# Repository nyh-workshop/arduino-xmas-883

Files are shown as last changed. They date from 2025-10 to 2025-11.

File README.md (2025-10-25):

# arduino-xmas-883
An improvisation of Myke Predko's "xmas" project in "Programming and Customizing the PIC Microcontroller 3rd Edition"

*Note*: This has been attempted in my other [repository](https://github.com/nyh-workshop/arduino-xmas-883-2023) too in 2023. However this one is a more detailed version and there are example STL and Gerber files for the materials.

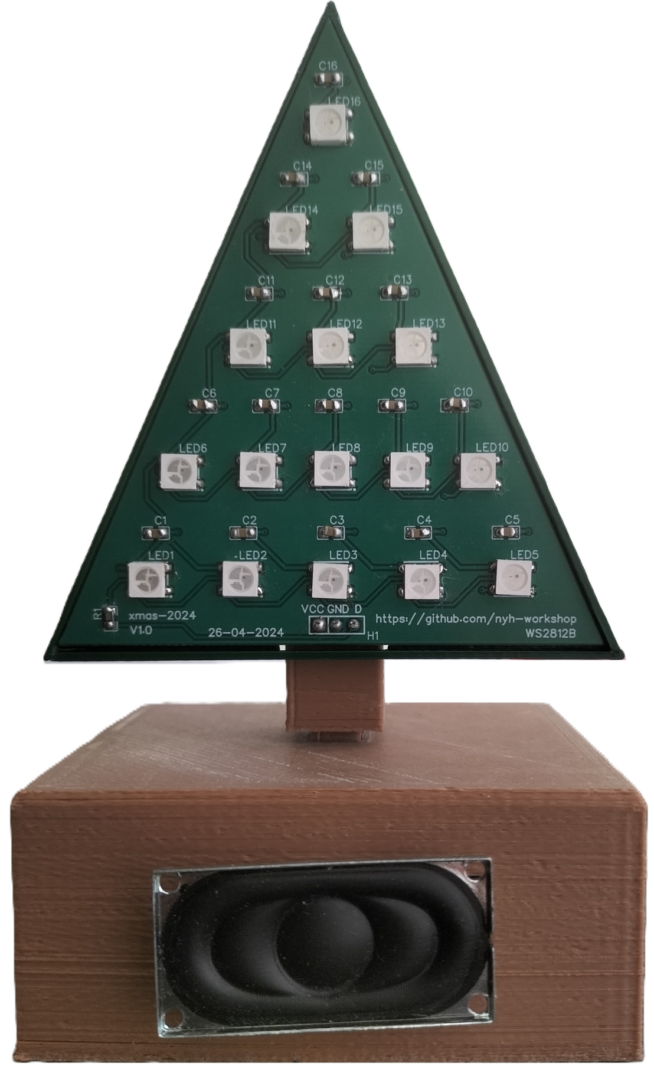
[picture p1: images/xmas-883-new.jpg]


## Introduction
About some 17 years back when I was in college, I chanced upon the Myke Predko's *Programming and Customizing the PIC Microcontroller* book in a local bookstore when I wanted to find study materials on microcontroller subject next semester.

It was extremely expensive over there in the place I stay and I could only glance a few pages of the book for previewing.

While admiring the projects in the book I saw one of the projects in page 883 called `xmas`, caught my attention and tried to remember as much details as possible.

Little me didn't know I could make things like that with a PIC microcontroller! Since I had a lot of space constraints at home, having a miniature, singing Christmas tree would be so cool on *my very own desk*!

I had attempted variants of this one almost each year - each of them are different every season, from one WAV file player, to another with different amount of LEDs, and with different microcontrollers from PIC32 to even ESP32. That too polished up some of the embedded skills of course!

## Details of the original `xmas`
### Random blinky lights
- From the schematic the author uses a `PIC16F84` microcontroller, coupled with a few `74LS373` shift registers to expand the I/O to accomodate those 16 LEDs.

- There is a pseudo-random number generator written to generate a random LED pattern, which is then manually bit-banged into the `74LS373`.

- The author mentioned about *wiring these 16 LEDs one-by-one* to the back of the tree, with many wires being used. Yes, it is tedious!

### Music
- It is a square-wave, monophonic. Bit-banged through a GPIO pin.

- The tone generation and reading the "notes" in the array is using a timer interrupt, possibly a `TMR0` one.

- The author recommends to use a beginner's Christmas music piano book to put these notes into the array manually. It has to be with the certain frequency range.

### Construction
- The original one uses **wood pieces and some paint**. Basically, the triangle one uses green and the base could be a brown to simulate the wood color.

- The PCB is manually sketched and etched locally. It is attached to the back of the tree "trunk" (*see diagram*).

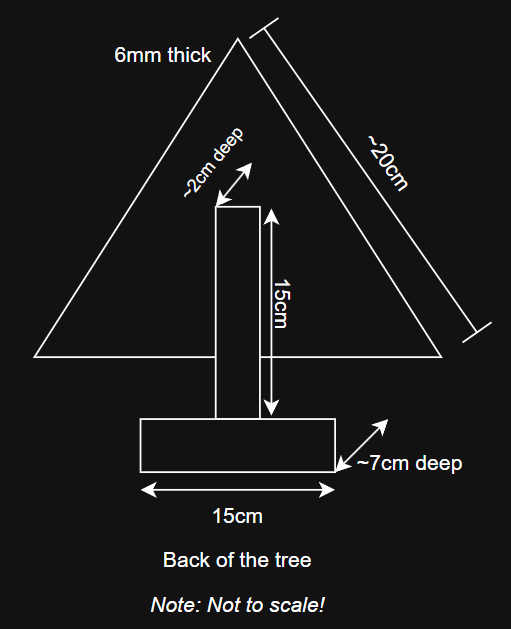
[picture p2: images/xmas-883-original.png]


### Power
- It is powered through the DC jack, with the casual 7805.

## Details of the improvised `xmas` in 2025
### Random blinky lights (and more colorful LEDs!)
- Using the [WS2811/WS2812 addressable LEDs](https://cdn-shop.adafruit.com/datasheets/WS2812.pdf). Saves me the time from wiring the LEDs and also these LEDs can display any 24-bit RGB color. Plus, many libraries such as [FastLED](https://fastled.io/) offers support for these LEDs without having to rewrite special LED effects again.

- Instead of a PIC microcontroller, a [Raspberry Pico 2](https://www.raspberrypi.com/products/raspberry-pi-pico-2/) is used instead with the [Arduino Pico library](https://github.com/earlephilhower/arduino-pico). There is PIO (Programmable I/O) modules that helps to generate WS2812 signals without CPU intervention.

- This blinky activity is entirely run on core0 of this microcontroller.

- Soldering them on a PCB (Gerber included here) is even easier. It's all on the board!

### Music
- This uses a [modified MicroDexed library](https://codeberg.org/nyh-workshop/MicroDexed) for the Raspberry Pico 2 Arduino platform. Basically it is a Yamaha DX7 emulator. This generates the popular FM soundwaves that you hear from the 80s music.

- And, of course we need the music notes inside! I have the [modified MD_MIDIFile that reads the MIDI from the Raspberry Pico 2's flash memory](https://github.com/nyh-workshop/MD_MIDIFile_LittleFS). This saves me the extra SD card that I might use later. There is an Arduino plugin that [uploads the files into the Pico 2's flash memory](https://github.com/earlephilhower/arduino-pico-littlefs-plugin) too.

- Best of all it covers most of the frequency of the music notes!

- It is output through the [MAX98357 module](https://learn.adafruit.com/adafruit-max98357-i2s-class-d-mono-amp/overview), with a small speaker.

- The music playing and the emulator is running on another core1 of this microcontroller.

### Power
- It is powered through the regular micro-USB.

### Construction
- The original one was a bit too big for my desk or on my shelves, so I made the tree smaller.

- It has a multi-purpose PCB mainboard (check the Hardware folder) where I can mount the Pico 2, the MAX98357 module, the optional [M5 Unit Synth](https://docs.m5stack.com/en/unit/Unit-Synth) connector and the WS2811 port there. Gerbers are included if you want to send it to popular PCB manufacturers.

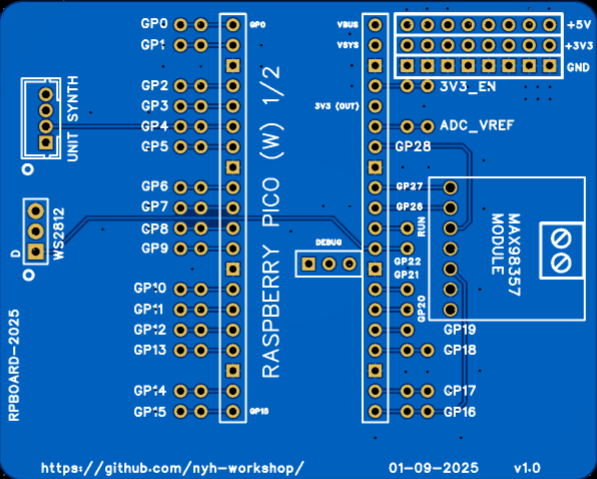
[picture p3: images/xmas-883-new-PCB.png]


- The WS2812 LEDs are mounted on the triangle portion of the tree. It is also a PCB for convenience sake.

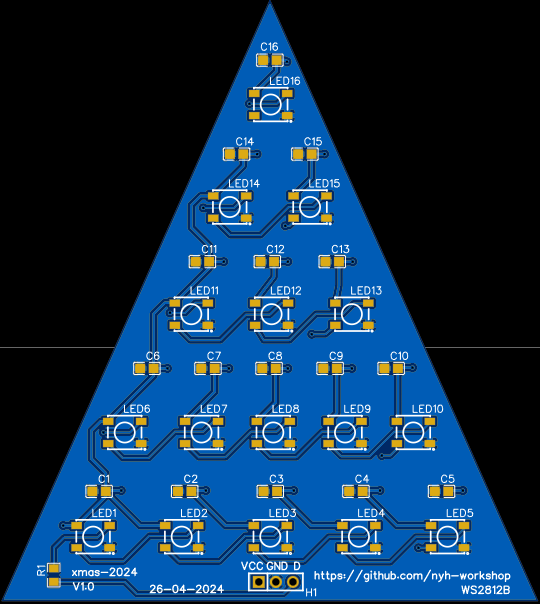
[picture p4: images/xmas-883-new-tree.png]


#### 3D printed tree and body

Since I can't *easily* source any wood pieces right now (or even before), it would be much easier if I just 3D-print it.

Similarly, I used the 3D-print `forest green` filament for the tree part (triangle), and the rest of the base and the trunk with `brown` filament.

I drew the parts using **Fusion 360**. It consists of the box that holds the mainboard box, its base, the trunk, and finally the tree part:

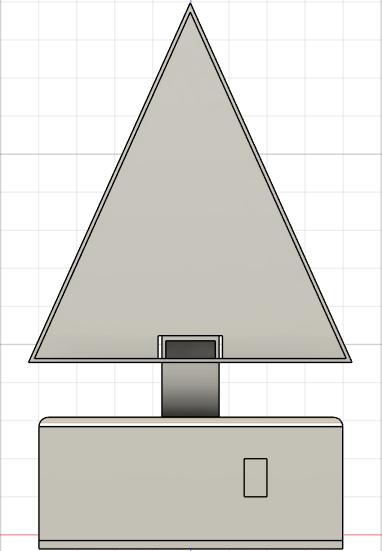
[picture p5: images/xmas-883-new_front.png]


From the original, mounting the PCB at the back of the tree is possibly impractical due to the location of the USB port. So, instead of putting it at the back, I choose to put it into the box, with the speaker glued to the front of the box.

Here is the construction when the board is fitted onto the box tray, with kapton tapes securing the wires:
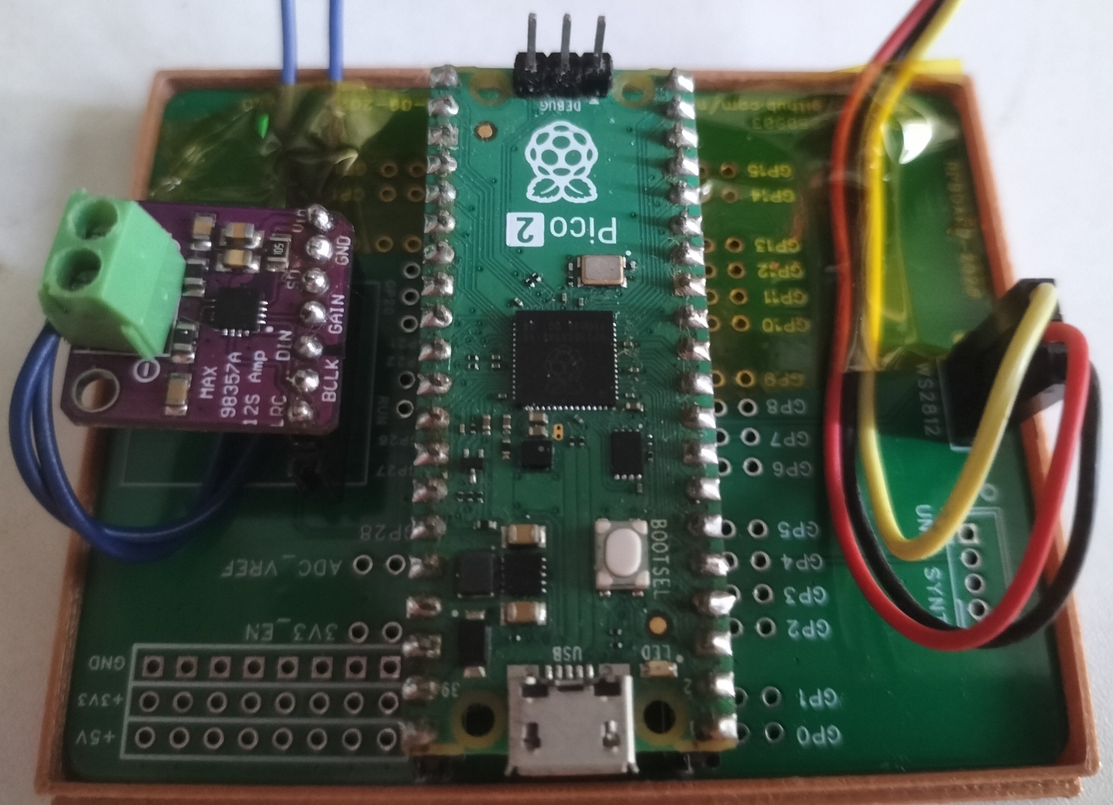
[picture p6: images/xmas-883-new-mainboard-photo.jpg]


To fit the PCB tree part to the 3D-print tree part (the triangle one), it is recommended that you use a double-sided tape to hold these together firmly.

There's a small rectangular hole in front of the box - it is slightly to the right. It is for the wires for the **small rectangular speaker (8 ohms, 2 watts)** and these are connected to the MAX98357 module's output. Again, use a double-sided tape to mount the speaker in front of the box.

### Software
For the LED part, the "blinky" is more than just blink now - there are all the colors in the world! I have used the FastLED example `Demoreel 100` and modified with some extra effects such as twinkling and such.

You can get the Christmas MIDIs from online, and then put these into the `data` folder before doing the `Upload LittleFS to Pico`. Make sure you have select the `Flash Size 128KB` or more at the `Tools` section.

For better playability of the MIDI file it is recommended that:
- Only one track is used. Multitrack may not work well on it.
- Keep the voices around 11 maximum.
- It does not play multiple instruments - only one is played. This will closely "imitate" the original design which is only a square-wave.

To modify the MIDI files back to one track and other things to accomodate the player, apps such as [MidiEditor](http://www.midieditor.org/) can be used.

As the player can support different instrument sounds, I have programmed it to play a different instrument every each time you switch it on. 

### Issues
- Since the MicroDexed is pretty CPU-intensive, I do expect a small amount of stuttering during playback. On testing, sometimes the MIDI player **behaved erratically** and have **too many notes ringing** at once. This causes the playback to stutter and eventually sounding off-key in a terrible manner. To minimize that unusual stuttering and stalling, I have enabled the `STUTTER_REBOOT` to **force reboot** the system when this happened. If it is disabled, the core1 will **halt** there while the LED blinks at the fastest way possible.

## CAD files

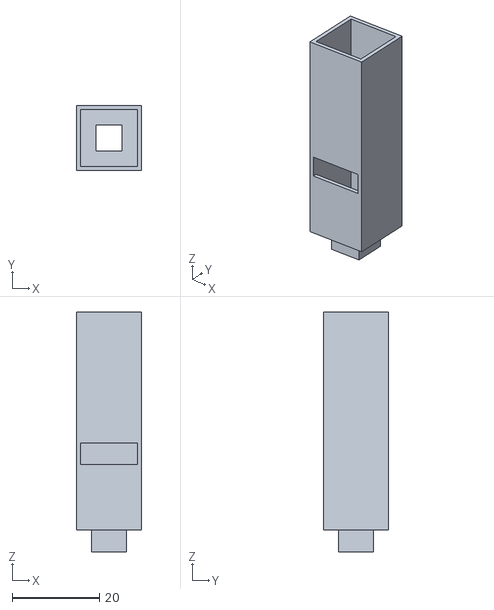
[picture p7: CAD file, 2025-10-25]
Hardware/v1.0/trunk_v1.0.stl
15.0 x 15.0 x 55.0

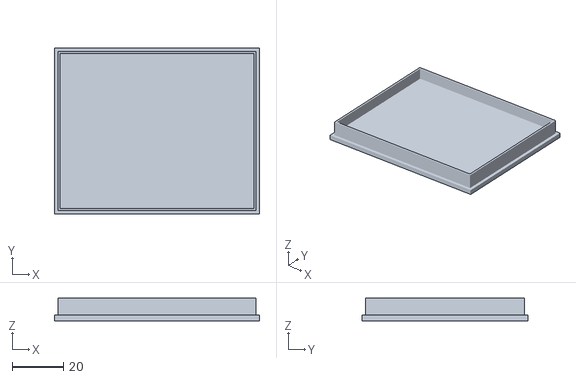
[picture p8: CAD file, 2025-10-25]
Hardware/v1.0/box_base_v1.0.stl
79.8 x 64.8 x 8.80

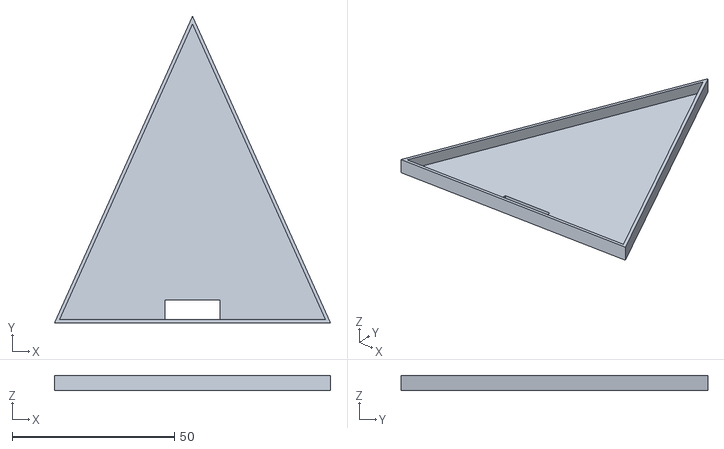
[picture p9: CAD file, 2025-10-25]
Hardware/v1.0/tree_v1.0.stl
85.0 x 94.4 x 4.50

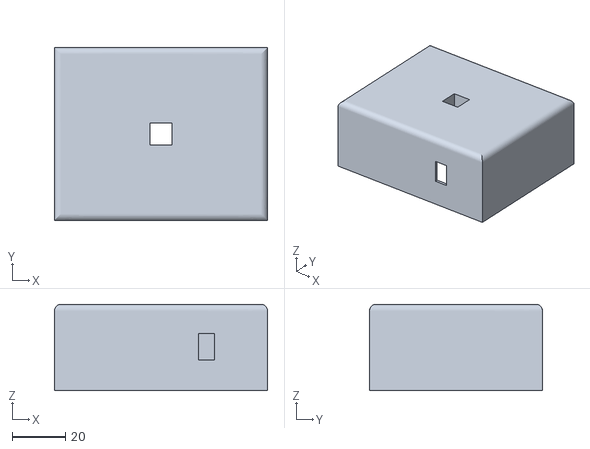
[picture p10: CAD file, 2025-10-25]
Hardware/v1.0/box_body_v1.0.stl
79.8 x 64.8 x 32.4

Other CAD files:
Hardware/v1.0/xmas-883_v1.0.f3d

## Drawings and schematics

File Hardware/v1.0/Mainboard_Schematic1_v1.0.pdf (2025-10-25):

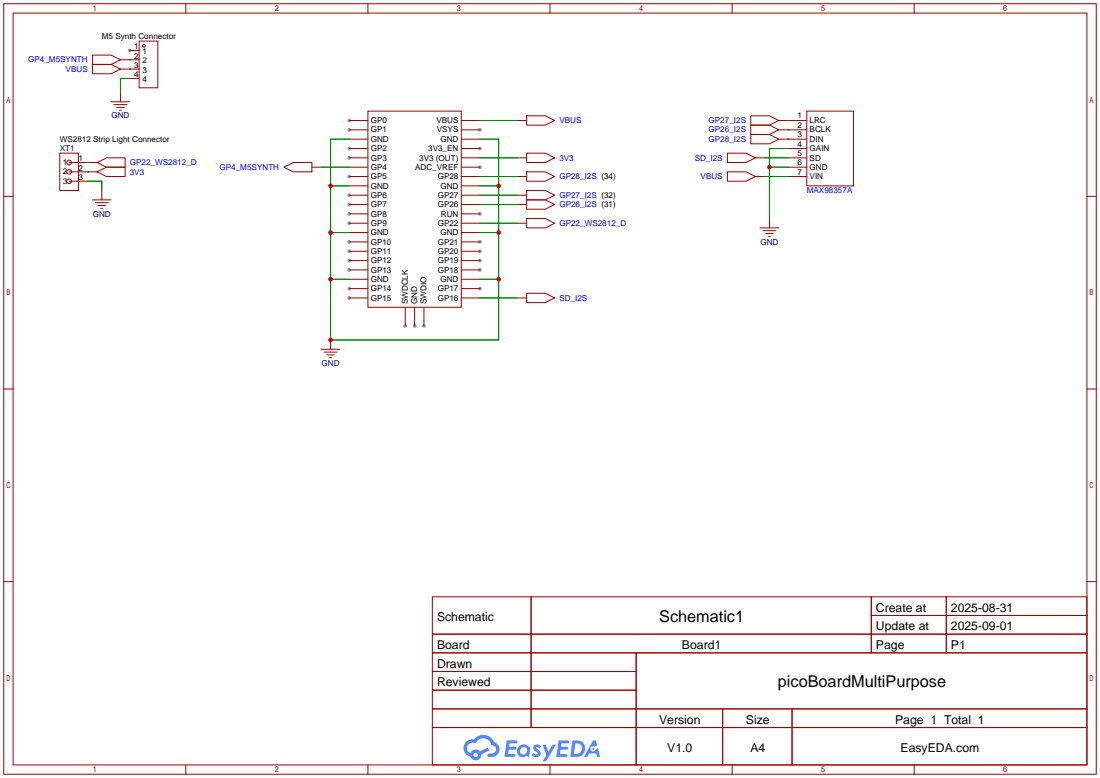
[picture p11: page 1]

Schematic | Schematic1 | Create at | 2025-08-31

Update at | 2025-09-01

Board | Board1 | Page | P1
Drawn | | picoBoardMultiPurpose
Reviewed

Version | Size | Page 1 Total 1
V1.0 | A4 | EasyEDA.com

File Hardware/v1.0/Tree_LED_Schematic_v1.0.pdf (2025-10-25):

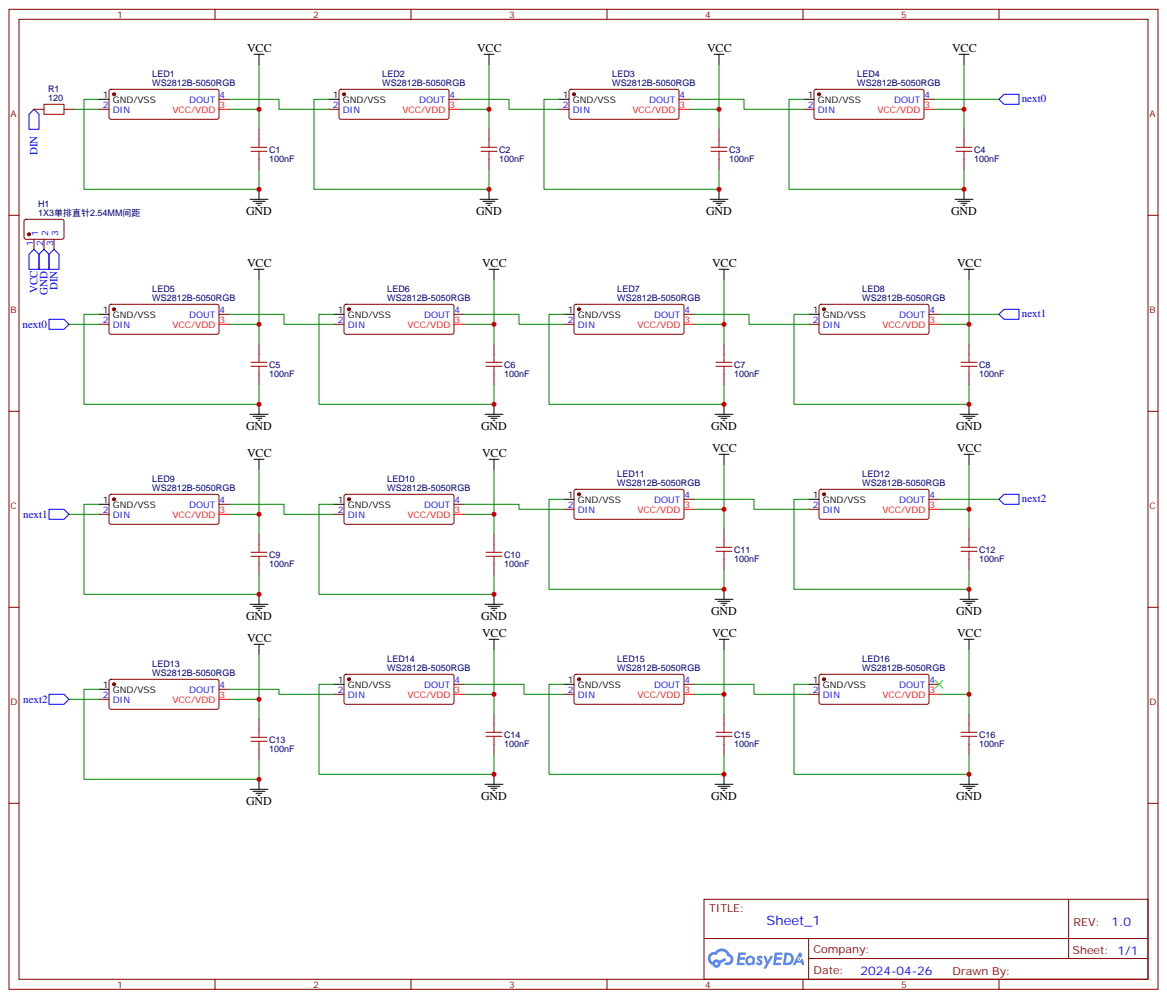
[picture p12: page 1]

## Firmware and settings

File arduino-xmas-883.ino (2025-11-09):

#include <Wire.h>
#include <limits.h>

#include <MD_MIDIFile.h>
#include <LittleFS.h>
#include <MicroDexedArduino.h>

#include "xmasLights_fastLED.h"
#include "midiJukebox.h"

// Note: Not sure why it doesn't work on Arduino Pico 5.3.0 or below! (Asserts on DMA setting at I2S)

#define LED_PIN 25
#define MAX98357_SD 16

constexpr bool DEBUG_MODE = true;

const int LED_TOGGLE_TIME_SETUP_DONE = 1000;
const int LED_TOGGLE_TIME_SETUP_ERROR = 250;
int LedToggleTime = 0;
bool LedState = false;
static uint32_t previousLedToggleTime = 0;

MicroDexedPicoI2sAudio* pMdI2s = nullptr;
Dexed* dexed = nullptr;
MD_MIDIFile SMF;
Dir rootDir;

uint32_t fill_audio_buffer = 0;
uint32_t t0, t1 = 0; // Time taken for MicroDexed engine to generate samples!
const uint16_t audio_block_time_us = 1000000 / (SAMPLE_RATE / AUDIO_BLOCK_SAMPLES);

const uint32_t MAX_STUTTERS_PER_SECOND = 16;
volatile uint32_t numberOfStuttersPerSecond = 0;
const bool STUTTER_REBOOT = true;

static enum { S_IDLE,
              S_PLAYING,
              S_NEXT,
              S_RESTART } state = S_IDLE;
static enum { SETUP_PROGRESS,
              SETUP_DONE_WITH_ERROR,
              SETUP_DONE } setupState = SETUP_PROGRESS;
static enum { DEXED_EPIANO = 11,
              DEXED_GUITAR = 12,
              DEXED_GLOCKENSPIEL_2 = 30,
              DEXED_HANDBELL_1 = 31 } dexedInstruments = DEXED_EPIANO;

uint8_t pickDexedVoice = DEXED_EPIANO;

void midiSilence(void)
// Turn everything off on every channel.
// Some midi files are badly behaved and leave notes hanging, so between songs turn
// off all the notes and sound
{
  midi_event ev;

  // All sound off
  // When All Sound Off is received all oscillators will turn off, and their volume
  // envelopes are set to zero as soon as possible.
  ev.size = 0;
  ev.data[ev.size++] = 0xb0;
  ev.data[ev.size++] = 120;
  ev.data[ev.size++] = 0;

  for (ev.channel = 0; ev.channel < 16; ev.channel++)
    midiCallback(&ev);
}

void midiCallback(midi_event* pev)
// Called by the MIDIFile library when a file event needs to be processed
// thru the midi communications interface.
// This callback is set up in the setup() function.
{
  // Define constants for MIDI channel voice message IDs
  const uint8_t NOTE_OFF = 0x80;  // note on
  const uint8_t NOTE_ON = 0x90;   // note off. NOTE_ON with velocity 0 is same as NOTE_OFF

  switch (pev->data[0]) {
    case NOTE_OFF:  // [1]=note no, [2]=velocity
      dexed->keyup(pev->data[1]);
      Serial.printf("NOTE_OFF ch: %d\n", pev->data[1]);
      break;

    case NOTE_ON:  // [1]=note_no, [2]=velocity
      // Note ON with velocity 0 is the same as off
      // Velocity is not included for now!
      dexed->keydown(pev->data[1], 127);
      Serial.printf("NOTE_ON trk: %d, ch: %d, no: %d\n", pev->track, pev->channel, pev->data[1]);
      break;

    default:
      break;
  }
}

void dexedPlaySamples() {
  // Main sound calculation
  fill_audio_buffer = micros();
  if ((i2s.availableForWrite() >= AUDIO_BLOCK_SAMPLES) && (fill_audio_buffer > (audio_block_time_us - 10))) {
    fill_audio_buffer = 0;
    t0 = micros();
    dexed->getSamples(AUDIO_BLOCK_SAMPLES, pMdI2s->audio_buffer);
    t1 = micros();
    if((t1 - t0) > audio_block_time_us)
    {
      // Serial.printf("Exceeded calculation time! %d microsecs.\n", (t1 - t0));
      numberOfStuttersPerSecond++;
    }
    pMdI2s->playSamples(AUDIO_BLOCK_SAMPLES, pMdI2s->audio_buffer);
  }
}

// Get random number from the rp2040/rp2350's hardware pseudo-random generator:
uint32_t getRandomNumber(uint32_t min, uint32_t max) {
  uint32_t randomNumber = rp2040.hwrand32();
  return (uint32_t)((randomNumber % (max - min + 1)) + min);
}

void nextSong(String midiFileName) {

  // Shut off notes at dexed during change
  // to prevent notes from going out of sync at next song!!
  dexed->notesOff();
  dexed->doRefreshVoice();
  dexed->panic();

  int err = SMF.load(midiFileName.c_str());
  if (midiFileName == "NoMoreMidiFileInDir") {
    Serial.println("No more midi files in directory!");
    return;
  }

  Serial.printf("Filename: %s\n", SMF.getFilename());
  Serial.printf("Format: %d\n", SMF.getFormat());

  if (err != MD_MIDIFile::E_OK)
    Serial.printf("SMF load error during playing: %d\n", err);
  else
    SMF.restart();
}

void stutterCheck()
{
  static uint32_t previousTime;
  if(millis() - previousTime >= 1000)
  {
    // Serial.printf("Stutters per second: %d\n", numberOfStuttersPerSecond);
    if(numberOfStuttersPerSecond > MAX_STUTTERS_PER_SECOND)
    {
      Serial.printf("Too much stuttering, exceeding max. number of stutter! %d\n", numberOfStuttersPerSecond);

      if(STUTTER_REBOOT)
        rp2040.reboot();
      else
      {
        while(1)
        {
           digitalWrite(LED_PIN, HIGH);
           delay(100);
           digitalWrite(LED_PIN, LOW);
           delay(100);
        }
      }
    }
    numberOfStuttersPerSecond = 0;
    previousTime = millis();
  }
}

void setup() {
  Serial.begin(115200);
  Serial1.begin(115200);

  uint32_t randomNumber = getRandomNumber(0, 3);

  delay(1000);

  Serial.println("arduino-xmas-883-2025");
  Serial.printf("Random number on startup: %d\n", randomNumber);

  pinMode(LED_PIN, OUTPUT);
  pinMode(WS2812_PIN, OUTPUT);

  Serial.println("Starting FastLED!");
  setupXmasLights();

  // Switch off the MAX98357 module first before init MicroDexed and I2S interface!
  pinMode(MAX98357_SD, OUTPUT);
  digitalWrite(MAX98357_SD, LOW);

  Serial.println(F("MicroDexed based on https://github.com/asb2m10/dexed"));
  Serial.println(F("(c)2018,2019-2025 H. Wirtz <wirtz@parasitstudio.de>"));
  Serial.println(F("https://github.com/dcoredump/MicroDexed"));
  Serial.printf("Max number of notes: %d\n", MAX_NOTES);
  Serial.println(F("<setup start>"));

  switch (randomNumber) {
    case 0:
      pickDexedVoice = DEXED_EPIANO;
      break;
    case 1:
      pickDexedVoice = DEXED_GUITAR;
      break;
    case 2:
      pickDexedVoice = DEXED_GLOCKENSPIEL_2;
      break;
    case 3:
      pickDexedVoice = DEXED_HANDBELL_1;
      break;
    default:
      break;
  }

  pMdI2s = new MicroDexedPicoI2sAudio(pickDexedVoice);
  dexed = new Dexed(SAMPLE_RATE);
  dexed->loadSysexVoice(pMdI2s->voice_data);

  Serial.println(F("<setup end>"));

  delay(250);

  digitalWrite(MAX98357_SD, HIGH);

  // Initialize LittleFS:
  if (!LittleFS.begin()) {
    Serial.println("LittleFS init fail!");
    state = S_IDLE;
    digitalWrite(MAX98357_SD, LOW);
    rp2040.fifo.push(SETUP_DONE_WITH_ERROR);
    return;
  }

  // Initialize MIDIFile:
  SMF.begin(&LittleFS);
  SMF.setMidiHandler(midiCallback);
  Serial.println("Start playing song now!");

  rootDir = LittleFS.openDir("/");

  // Load a first MIDI file from there:
  // Jukebox continuously plays next MIDI file if there is
  // one working MIDI file loaded for the first time.
  String midiFileName = getNextMidiFileNameFromDir(rootDir);
  int err = SMF.load(midiFileName.c_str());

  if (err != MD_MIDIFile::E_OK) {
    Serial.printf("SMF load error: %d\n", err);
    state = S_IDLE;
    digitalWrite(MAX98357_SD, LOW);
    rp2040.fifo.push(SETUP_DONE_WITH_ERROR);
    return;
  }

  Serial.printf("Filename: %s\n", SMF.getFilename());
  Serial.printf("Format: %d\n", SMF.getFormat());

  state = S_PLAYING;

  rp2040.fifo.push(SETUP_DONE);
}

void loop() {
  xmasLightsLoop();

  if (millis() - previousLedToggleTime >= LedToggleTime) {
    LedState = LedState ^ 1;
    digitalWrite(LED_PIN, LedState);
    previousLedToggleTime = millis();
  }
}

void setup1() {

  // put your setup code here, to run once:
  while (!rp2040.fifo.available())
    ;

  if (rp2040.fifo.pop() == SETUP_DONE) {
    Serial.println("Setup done! :D");
    LedToggleTime = LED_TOGGLE_TIME_SETUP_DONE;
  } else {
    Serial.println("Setup error! Please check setup!");
    LedToggleTime = LED_TOGGLE_TIME_SETUP_ERROR;
  }
}

void loop1() {
  // put your main code here, to run repeatedly:
  if (DEBUG_MODE) {
    if (Serial.available() > 0) {
      char incomingChar = Serial.read();
      if (incomingChar == 's')
        state = S_NEXT;
      else if (incomingChar == 'r')
        state = S_RESTART;
    }
  }
  switch (state) {
    case S_IDLE:
      delay(500);
      break;
    case S_PLAYING:
      if (!SMF.isEOF()) {
        dexedPlaySamples();
        SMF.getNextEvent();
        stutterCheck();
      } else {
        // Reached end of file.
        // Play next file, and if no next file, go idle mode!
        SMF.close();
        SMF.pause(true);
        midiSilence();

        String midiFileName = getNextMidiFileNameFromDir(rootDir);
        if (midiFileName == "NoMoreMidiFileInDir") {
          Serial.println("Playing done! Idle mode now...");
          // Switch off the MAX98357 module at idle!
          digitalWrite(MAX98357_SD, LOW);
          state = S_IDLE;
        } else {
          Serial.println("Play song done! Next song...");
          delay(1000);
          nextSong(midiFileName);
          state = S_PLAYING;
          SMF.pause(false);
        }
      }
      break;
    case S_NEXT:
      {
        Serial.println("Skip to next song...");

        SMF.close();
        SMF.pause(true);
        midiSilence();

        delay(100);

        String midiFileName = getNextMidiFileNameFromDir(rootDir);
        nextSong(midiFileName);
        state = S_PLAYING;
        SMF.pause(false);
      }
      break;
    case S_RESTART:
      Serial.println("Restarting song...");
      midiSilence();
      dexed->notesOff();
      dexed->doRefreshVoice();
      dexed->panic();
      SMF.restart();
      delay(100);
      state = S_PLAYING;
      break;
    default:
      break;
  }
}

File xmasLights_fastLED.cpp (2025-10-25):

#include "xmasLights_fastLED.h"

// FastLED "100-lines-of-code" demo reel, showing just a few 
// of the kinds of animation patterns you can quickly and easily 
// compose using FastLED.  
//
// This example also shows one easy way to define multiple 
// animations patterns and have them automatically rotate.
//
// -Mark Kriegsman, December 2014

#if defined(FASTLED_VERSION) && (FASTLED_VERSION < 3001000)
#warning "Requires FastLED 3.1 or later; check github for latest code."
#endif

CRGBArray<NUM_LEDS> leds;
CRGBArray<NUM_LEDS> ledsTwinkle;

CRGBPalette16 gCurrentPalette;
CRGBPalette16 gTargetPalette;

#define BRIGHTNESS 96
#define FRAMES_PER_SECOND 120

#define AUTO_SELECT_BACKGROUND_COLOR 0

// Overall twinkle speed.
// 0 (VERY slow) to 8 (VERY fast).
// 4, 5, and 6 are recommended, default is 4.
//#define TWINKLE_SPEED 4
auto TWINKLE_SPEED = 4;

auto FADE_BPM = 25;

// Overall twinkle density.
// 0 (NONE lit) to 8 (ALL lit at once).
// Default is 5.
#define TWINKLE_DENSITY 5

// How often to change color palettes.
#define SECONDS_PER_PALETTE  30
// Also: toward the bottom of the file is an array
// called "ActivePaletteList" which controls which color
// palettes are used; you can add or remove color palettes
// from there freely.

// Background color for 'unlit' pixels
// Can be set to CRGB::Black if desired.
CRGB gBackgroundColor = CRGB::Black;
// Example of dim incandescent fairy light background color
// CRGB gBackgroundColor = CRGB(CRGB::FairyLight).nscale8_video(16);

// If AUTO_SELECT_BACKGROUND_COLOR is set to 1,
// then for any palette where the first two entries
// are the same, a dimmed version of that color will
// automatically be used as the background color.
#define AUTO_SELECT_BACKGROUND_COLOR 0

// If COOL_LIKE_INCANDESCENT is set to 1, colors will
// fade out slighted 'reddened', similar to how
// incandescent bulbs change color as they get dim down.
#define COOL_LIKE_INCANDESCENT 1

void setupXmasLights() {
  // put your setup code here, to run once:
  delay(500);

  // tell FastLED about the LED strip configuration
  FastLED.addLeds<LED_TYPE, DATA_PIN, COLOR_ORDER>(leds, NUM_LEDS).setCorrection(TypicalLEDStrip);
  
  // set master brightness control
  FastLED.setBrightness(BRIGHTNESS);

  chooseNextColorPalette(gTargetPalette);
}

// List of patterns to cycle through.  Each is defined as a separate function below.
typedef void (*SimplePatternList[])();
SimplePatternList gPatterns = { fairyS, alt2colorsRedBlue, fadeYellow, rainbow,
                                fairyS, fadeRed, alt2colorsBlueGreen, fairyS,
                                fadeWhite, rainbowWithGlitter, fadeBlue, alt2colorsRedGreen,
                                confetti, fairyS, alt2colorsRedBlue, sinelon,
                                fairyS, fadeGreen, alt2colorsBlueGreen, fairyS,
                                juggle, alt2colorsRedGreen, bpm, fairyS };

uint8_t gCurrentPatternNumber = 0;  // Index number of which pattern is current
uint8_t gHue = 0;                   // rotating "base color" used by many of the patterns

void xmasLightsLoop() {
  static bool isTwinkle = false;

  EVERY_N_SECONDS(60) {
    isTwinkle ^= 1;
  }

  if (!isTwinkle)
  {
    // put your main code here, to run repeatedly:
    // Call the current pattern function once, updating the 'leds' array
    gPatterns[gCurrentPatternNumber]();

    // send the 'leds' array out to the actual LED strip
    FastLED.show();
    // insert a delay to keep the framerate modest
    FastLED.delay(1000 / FRAMES_PER_SECOND);

    // do some periodic updates
    EVERY_N_MILLISECONDS(20) {
      gHue++;
    }  // slowly cycle the "base color" through the rainbow
    EVERY_N_SECONDS(10) {
      nextPattern();
    }  // change patterns periodically
  }
  else
  {
    // Every 5 minutes randomize twinkle speed:
    EVERY_N_SECONDS( 300 ) {
        TWINKLE_SPEED = random8(2,6);
    }

    EVERY_N_SECONDS( SECONDS_PER_PALETTE ) {
      chooseNextColorPalette( gTargetPalette );
    }

    EVERY_N_MILLISECONDS( 10 ) {
      nblendPaletteTowardPalette( gCurrentPalette, gTargetPalette, 12);
    }

    drawTwinkles(leds);

    FastLED.show();
  }
}

void nextPattern() {
  // add one to the current pattern number, and wrap around at the end
  gCurrentPatternNumber = (gCurrentPatternNumber + 1) % ARRAY_SIZE_FASTLED(gPatterns);
}

void fadeYellow() {
  uint8_t beat = beatsin8(FADE_BPM, 0, 255);
  fill_solid(leds, NUM_LEDS, CRGB(beat, beat, 0));
}

void fadeRed() {
  uint8_t beat = beatsin8(FADE_BPM, 0, 255);
  fill_solid(leds, NUM_LEDS, CRGB(beat, 0, 0));
}

void fadeBlue() {
  uint8_t beat = beatsin8(FADE_BPM, 0, 255);
  fill_solid(leds, NUM_LEDS, CRGB(0, 0, beat));
}

void fadeGreen() {
  uint8_t beat = beatsin8(FADE_BPM, 0, 255);
  fill_solid(leds, NUM_LEDS, CRGB(0, beat, 0));
}

void fadeWhite() {
  uint8_t beat = beatsin8(FADE_BPM, 0, 255);
  fill_solid(leds, NUM_LEDS, CRGB(beat, beat, beat));
}

void alt2colorsRedBlue() {
  unsigned long currTime;
  static unsigned long prevTime;
  static bool flip;

  currTime = millis();

  if ((currTime - prevTime) >= 1000) {

    flip ^= 1;
    if (flip) {
      for (uint16_t i = 0; i < NUM_LEDS; i++) {
        leds[i] = (i % 2 == 0) ? CRGB::Red : CRGB::Blue;
      }
    } else {
      for (uint16_t i = 0; i < NUM_LEDS; i++) {
        leds[i] = (i % 2 == 0) ? CRGB::Blue : CRGB::Red;
      }
    }

    prevTime = currTime;
  }
}

void alt2colorsRedGreen() {
  static bool flip;

  EVERY_N_SECONDS(1) {
    flip ^= 1;
    if (flip) {
      for (uint16_t i = 0; i < NUM_LEDS; i++) {
        leds[i] = (i % 2 == 0) ? CRGB::Red : CRGB::Green;
      }
    } else {
      for (uint16_t i = 0; i < NUM_LEDS; i++) {
        leds[i] = (i % 2 == 0) ? CRGB::Green : CRGB::Red;
      }
    }
  }
}

void alt2colorsBlueGreen() {
  static bool flip;

  EVERY_N_SECONDS(1) {
    flip ^= 1;
    if (flip) {
      for (uint16_t i = 0; i < NUM_LEDS; i++) {
        leds[i] = (i % 2 == 0) ? CRGB::Blue : CRGB::Green;
      }
    } else {
      for (uint16_t i = 0; i < NUM_LEDS; i++) {
        leds[i] = (i % 2 == 0) ? CRGB::Green : CRGB::Blue;
      }
    }
  }
}

void rainbow() {
  // FastLED's built-in rainbow generator
  fill_rainbow(leds, NUM_LEDS, gHue, 7);
}

void rainbowWithGlitter() {
  // built-in FastLED rainbow, plus some random sparkly glitter
  rainbow();
  addGlitter(80);
}

void addGlitter(fract8 chanceOfGlitter) {
  if (random8() < chanceOfGlitter) {
    leds[random16(NUM_LEDS)] += CRGB::White;
  }
}

void confetti() {
  // random colored speckles that blink in and fade smoothly
  fadeToBlackBy(leds, NUM_LEDS, 10);
  int pos = random16(NUM_LEDS);
  leds[pos] += CHSV(gHue + random8(64), 200, 255);
}

void sinelon() {
  // a colored dot sweeping back and forth, with fading trails
  fadeToBlackBy(leds, NUM_LEDS, 20);
  int pos = beatsin16(13, 0, NUM_LEDS - 1);
  leds[pos] += CHSV(gHue, 255, 192);
}
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
